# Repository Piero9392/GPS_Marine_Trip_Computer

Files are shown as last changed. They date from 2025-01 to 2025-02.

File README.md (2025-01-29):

# GPS Marine Trip Computer 🚤



This project is a fully functional GPS Marine Trip Computer designed for boats or other purposes. It displays real-time speed, direction, temperature, time, total odometer reading, total engine operating hours, and trip distance on an ILI9341 TFT display.

## Features
* **Speed Monitoring**: Real-time speed display in km/h.
* **Trip and Total Odometers**: Track current trip distance and total traveled distance.
* **Runtime Tracker**: Records and displays the total runtime of the engine.
* **Temperature Display**: Real-time water or ambient temperature measurement using a DS18B20 sensor.
* **GPS Data**: Displays location-based data, including time (with timezone adjustment) and heading direction.
* **EEPROM Data Persistence**: Saves total distance and runtime data to EEPROM for retrieval after a power cycle.
* **3D Printable Case**: Includes 3D files for printing a custom case and lid.

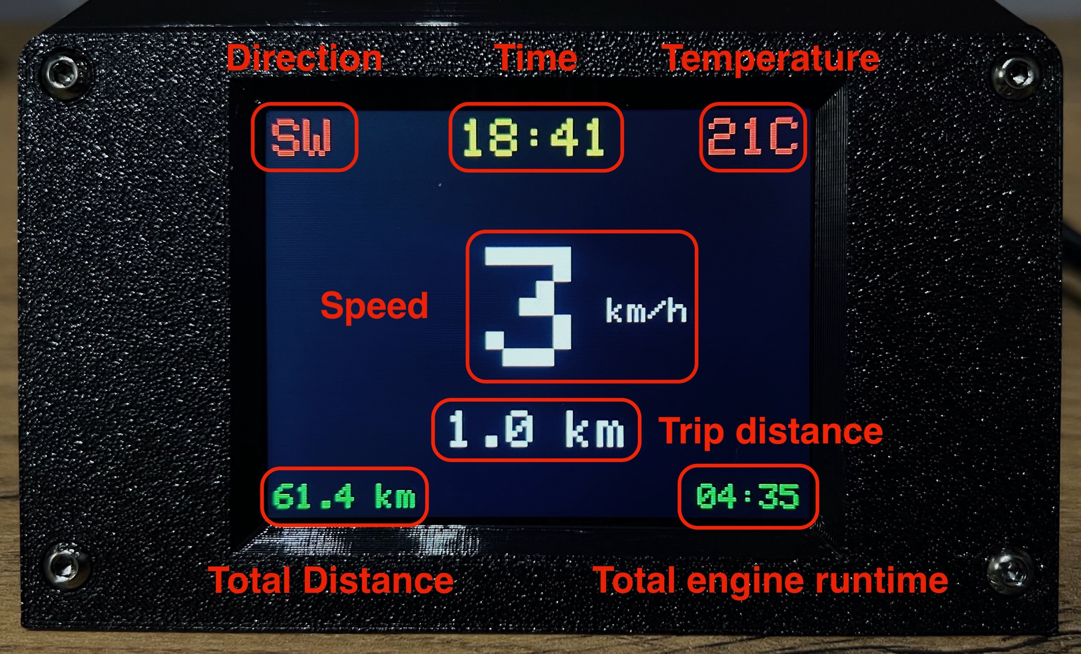
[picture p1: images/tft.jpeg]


## Hardware Requirements
* **Micrcontroller**: ESP32 WROOM 30 pins
* **Display**: ILI9341 TFT 2.8inch 240x320
* **GPS Module**: NEO-6M
* **Temperature Sensor**: DS18B20
* **4.7 kΩ pull-up resistor**
* **PCB breadboard**: 60x40mm
* **LC filter (inductor-capacitor filter)**: 0-50V, 2A
* **DC-DC converter**: MP1584 (Input: 4.5-28V, Output: set 3.3/5.0V, 2A)
* **Other Components**: AWG wires, power source, connectors, screws

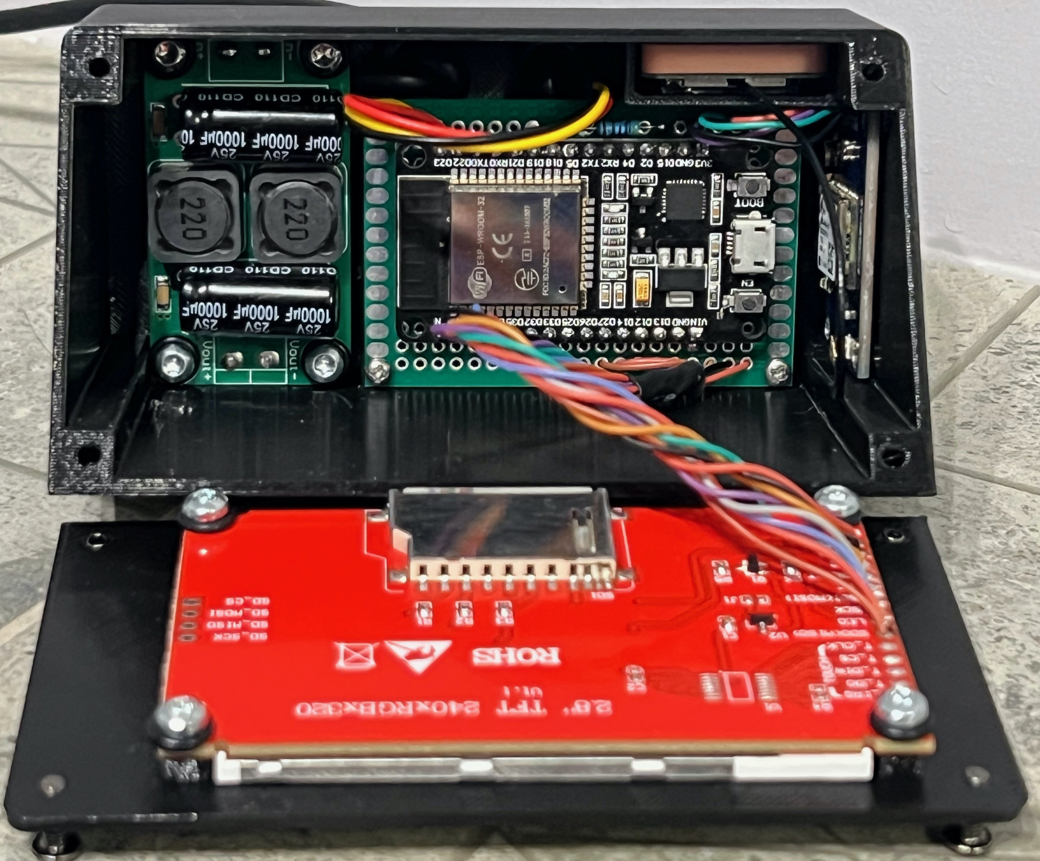
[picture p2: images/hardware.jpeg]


## Libraries Used
* `Arduino.h` - Core Arduino functionality.
* `Adafruit_GFX` - Graphs library for the TFT display.
* `Adafruit_ILI9341` - ILI9341 display driver library.
* `TinyGPS++` - GPS data parsing library.
* `SoftwareSerial` - Serial communation for the GPS module.
* `DallasTemperature` - Temperature sensor library for DS18B20.
* `OneWire` - OneWire protocol library for DS18B20 sensor.
* `EEPROM` - Library to read/write data from/to the EEPROM.

## Hardware Connections

###  Filter
* Connect the **input** of the LC filter to your **power source** (e.g., 12V boat battery).
* The LC filter is **placed before** the DC-DC converter to smooth out power supply noise.
* **Benefits of LC Filtering:**
  * **Filters out high-frequency noise** from the engine.
  * **Prevents voltage spikes** that could damage components.
  * **Improves power stability** for reliable operation.

### DC-DC Converter (MP1584)
1. **Connect the input** (VIN and GND) of the MP1584 to the **output of the LC filter**.
2. Ensure the power source voltage is within **4.5V – 28V**.
3. **Adjust Output Voltage:**
   * Connect a **multimeter** to the output terminals.
   * Turn the **adjustment potentiometer** to set the output voltage to **3.3V**.
   * Verify the voltage **before connecting the ESP32**.
4. Ensure the converter provides at least **500mA (preferably 1A or more)**.

⚠ **Note:** Do not power the ESP32 with **5V** unless using the **5V** pin (some ESP32 modules support both **5V** and **3.3V** inputs).

### Component Wiring

#### 🖥 TFT Display (ILI9341) SPI-connection:
* **MOSI**: ESP32 GPIO 23
* **MISO**: ESP32 GPIO 19
* **SCK**: ESP32 GPIO 18
* **CS**: ESP32 GPIO 5
* **RESET**: ESP32 GPIO 4
* **DC**: ESP32 GPIO 2
* **LED**: DC-DC converter Output `+`
* **VIN**: DC-DC converter Output `+`
* **GND**: DC-DC converter Output `-`

#### 📡 GPS module (Neo-6M):
* **VCC**: DC-DC converter Output `+`
* **GND**: DC-DC converter Output `-`
* **RX**: ESP32 GPIO 17 (TX2)
* **TX**: ESP32 GPIO 16 (RX2)

#### 🌡 Temperature sensor (DS18B20):
* **VCC**: DC-DC converter Output `+`
* **GND**: DC-DC converter Output `-`
* **Data**: ESP32 GPIO 15

⚠ **Note**: A **4.7kΩ pull-up resistor** is required between Data and VCC.

## How It Works
* **GPS Module**: Continuously streams data (speed, direction, time), processed using `TinyGPS++`.
* **Temperature Sensor (DS18B20)**: Measures water/ambient temperature, updated every second.
* **Display Updates**: Data is shown on the **ILI9341 TFT display**.
* **Logging**: Distance traveled and engine runtime are logged in EEPROM to persist after power cycles.
* **Effient Data Updates**: Display refreshes only on signifant data changes to optimize performance.

## Setup and Installation
1. **Install Libraries**: Install required libraries in Arduino IDE.
2. **Connect Components**: Follow the wiring diagram.
3. **Upload Code**: Flash the provided code onto the ESP32.
4. **GPS Module**: Ensure a **clear view of the sky** for accurate tracking.
5. **Power On**: Start tracking speed, temperature, and trip data!

## 3D Printable Case
This project includes **3D files for printing** a custom case and lid for protection and easy mounting.

## Future Improvements
* **External Storage**: Add SD card support to log trip data.
* **Mobile Connectivity**: Integrate **Bluetooth or Wi-Fi** for app-based tracking.
* **Additional Metrs**: Implement altitude tracking and course history.

## Author
**Igor Kolesnykov**

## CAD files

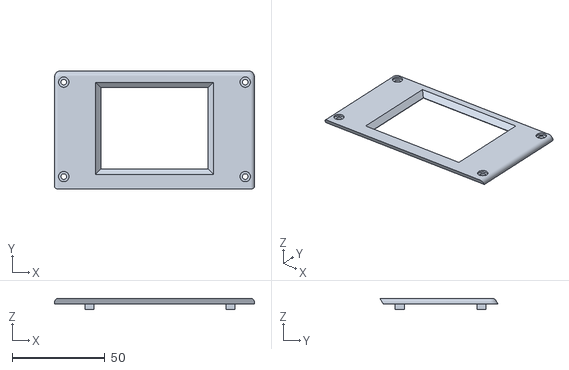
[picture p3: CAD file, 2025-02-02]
Speedometer_face_lid.stl
108.0 x 63.7 x 6.00

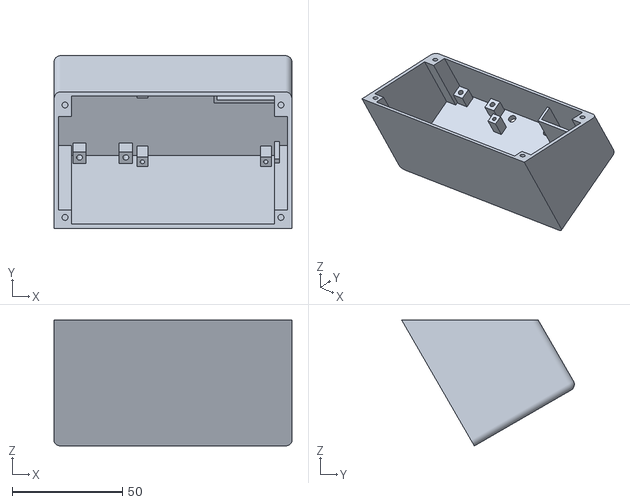
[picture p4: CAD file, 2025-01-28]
speedometer_box.stl
108.0 x 78.4 x 57.2

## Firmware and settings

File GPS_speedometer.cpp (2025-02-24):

#include <Arduino.h>
#include <SPI.h>
#include <Adafruit_GFX.h>
#include <Adafruit_ILI9341.h>
#include <TinyGPS++.h>
#include <SoftwareSerial.h>
#include <HardwareSerial.h>
#include <EEPROM.h>
#include <OneWire.h>
#include <DallasTemperature.h>

#define TFT_CS 5
#define TFT_RST 4
#define TFT_DC 2

Adafruit_ILI9341 tft(TFT_CS, TFT_DC, TFT_RST);
TinyGPSPlus gps;
HardwareSerial gpsSerial(1);

#define ONE_WIRE_BUS 15  // Change to the pin you are using for DS18B20 data
OneWire oneWire(ONE_WIRE_BUS);
DallasTemperature sensors(&oneWire);

unsigned long lastUpdateTime = 0;
String lastTimeDisplay = "";
const int timezoneOffset = 2; // Time correction for Ukraininan  time zone +2h

float tripDistance = 0;  // Distance for the current trip
float totalDistance = 0; // Total distance over all sessions
unsigned long totalRuntimeMillis = 0;

const int EEPROM_SIZE = 16;  // Increased size to store both runtime and totalDistance

void setupEEPROM() {
  EEPROM.begin(EEPROM_SIZE);
  totalRuntimeMillis = EEPROM.readULong(0);
  EEPROM.get(8, totalDistance);
}

void updateEEPROMData(unsigned long currentSessionMillis) {
  totalRuntimeMillis += currentSessionMillis;
  EEPROM.writeULong(0, totalRuntimeMillis);
  EEPROM.put(8, totalDistance);
  EEPROM.commit();
}

void speed(double speed) {
  static String lastSpeedText = "";  // Track the last displayed speed
  char speedText[10];
  sprintf(speedText, "%d", (int)speed);
  String currentSpeedText = String(speedText);

  if (lastSpeedText != currentSpeedText) {
    int16_t x1, y1;
    uint16_t w, h;
    tft.setTextSize(12);
    tft.getTextBounds(speedText, 0, 0, &x1, &y1, &w, &h);
    tft.fillRect(0, (tft.height() - h) / 2 - 10, tft.width(), h + 20, ILI9341_BLACK);

    int centerX = (tft.width() - w) / 2;
    int centerY = (tft.height() - h) / 2;

    tft.setCursor(centerX, centerY);
    tft.setTextColor(ILI9341_WHITE, ILI9341_BLACK);
    tft.print(speedText);

    tft.setTextSize(2);
    tft.setCursor(centerX + w, centerY + 30);
    tft.print(" km/h");

    lastSpeedText = currentSpeedText;
  }
}

void tripOdometer(float distanceKm) {
  static float lastTripDisplay = -1.0;
  if (fabs(distanceKm - lastTripDisplay) > 0.1) {  // Update only if a significant change
    char buffer[10];
    snprintf(buffer, sizeof(buffer), "%.1f km", distanceKm);
    tft.setTextSize(3);
    tft.setTextColor(ILI9341_WHITE, ILI9341_BLACK);
    int16_t x1, y1;
    uint16_t w, h;
    tft.getTextBounds(buffer, 0, 0, &x1, &y1, &w, &h);
    int centerX = (tft.width() - w) / 2;
    int centerY = ((tft.height() + h) / 2) + 45;
    tft.fillRect(centerX, centerY - h, w, h, ILI9341_BLACK);  // Clear previous value
    tft.setCursor(centerX, centerY);
    tft.print(buffer);
    lastTripDisplay = distanceKm;
  }
}

void totalOdometer(float distanceKm) {
  static float lastOdometerDisplay = -1.0;
  if (fabs(distanceKm - lastOdometerDisplay) > 0.1) {  // Update only if a significant change
    char buffer[10];
    snprintf(buffer, sizeof(buffer), "%.1f km", distanceKm);
    tft.setTextSize(2);
    tft.setTextColor(ILI9341_GREEN, ILI9341_BLACK);
    int16_t x1, y1;
    uint16_t w, h;
    tft.getTextBounds(buffer, 0, 0, &x1, &y1, &w, &h);
    tft.fillRect(5, tft.height() - 20, w, h, ILI9341_BLACK);  // Clear previous value
    tft.setCursor(5, tft.height() - 20);
    tft.print(buffer);
    lastOdometerDisplay = distanceKm;
  }
}

void totalRuntime() {
  static String lastRuntimeDisplay = "";  // Track the last displayed runtime
  unsigned long totalMinutes = totalRuntimeMillis / 60000;
  unsigned long hours = totalMinutes / 60;
  unsigned long minutes = totalMinutes % 60;

  char runtimeBuffer[6];
  snprintf(runtimeBuffer, sizeof(runtimeBuffer), "%02lu:%02lu", hours, minutes);
  String currentRuntimeDisplay = String(runtimeBuffer);

  if (currentRuntimeDisplay != lastRuntimeDisplay) {
    tft.setTextSize(2);
    tft.setTextColor(ILI9341_GREEN, ILI9341_BLACK);
    int16_t x1, y1;
    uint16_t w, h;
    tft.getTextBounds(runtimeBuffer, 0, 0, &x1, &y1, &w, &h);
    tft.fillRect(tft.width() - w - 5, tft.height() - 20, w, h, ILI9341_BLACK);
    tft.setCursor(tft.width() - w - 5, tft.height() - 20);
    tft.print(runtimeBuffer);
    lastRuntimeDisplay = currentRuntimeDisplay;
  }
}

void time() {
  if (gps.time.isValid()) {
    int hour = gps.time.hour() + timezoneOffset; // Time zone correction (for Ukraine +2 hours)
    if (hour >= 24) {
      hour -= 24;
    }
    char timeBuffer[6];
    snprintf(timeBuffer, sizeof(timeBuffer), "%02d:%02d", hour, gps.time.minute());

    if (lastTimeDisplay != String(timeBuffer)) {
      tft.setTextSize(4);
      tft.setTextColor(ILI9341_YELLOW, ILI9341_BLACK);
      int16_t x1, y1;
      uint16_t w, h;
      tft.getTextBounds(timeBuffer, 0, 0, &x1, &y1, &w, &h);
      tft.fillRect((tft.width() - w) / 2, 5, w, h, ILI9341_BLACK);
      tft.setCursor((tft.width() - w) / 2, 5);
      tft.print(timeBuffer);
      lastTimeDisplay = String(timeBuffer);
    }
  }
}

void direction() {
  if (gps.course.isValid()) {
    String direction;
    double course = gps.course.deg();

    if ((course >= 337.5) || (course < 22.5)) direction = "N";
    else if (course < 67.5) direction = "NE";
    else if (course < 112.5) direction = "E";
    else if (course < 157.5) direction = "SE";
    else if (course < 202.5) direction = "S";
    else if (course < 247.5) direction = "SW";
    else if (course < 292.5) direction = "W";
    else direction = "NW";

    static String lastDirectionDisplay = "";
    if (lastDirectionDisplay != direction) {
      tft.setTextSize(4);
      tft.setTextColor(ILI9341_RED, ILI9341_BLACK);
      int16_t x1, y1;
      uint16_t w, h;
      tft.getTextBounds(direction.c_str(), 10, 10, &x1, &y1, &w, &h);
      tft.fillRect(5, 5, w + 20, h, ILI9341_BLACK);  // Clear previous direction
      tft.setCursor(5, 5);
      tft.print(direction);
      lastDirectionDisplay = direction;
    }
  }
}

void temperature() {
  sensors.requestTemperatures();
  float tempC = sensors.getTempCByIndex(0);
  static int lastTemperature = -999;
  static unsigned long lastTempUpdateTime = 0;
  int currentTemperature = static_cast<int>(round(tempC));

  if (abs(currentTemperature - lastTemperature) >= 1 && (millis() - lastTempUpdateTime >= 1000)) {
    char tempBuffer[10];
    snprintf(tempBuffer, sizeof(tempBuffer), "%dC", currentTemperature);
    tft.setTextSize(4);
    tft.setTextColor(ILI9341_RED, ILI9341_BLACK); 

    int16_t x1, y1;
    uint16_t w, h;
    tft.getTextBounds(tempBuffer, 0, 0, &x1, &y1, &w, &h);

    int rectWidth = 100;
    int rectHeight = 35;
    int x = tft.width() - rectWidth;
    int y = 0;
    tft.fillRect(x, y, rectWidth, rectHeight, ILI9341_BLACK);
    tft.setCursor(tft.width() - w - 5, 5);
    tft.print(tempBuffer);

    lastTemperature = currentTemperature;
    lastTempUpdateTime = millis();
  }
}
  
void setup() {
  Serial.begin(115200);
  gpsSerial.begin(9600, SERIAL_8N1, 16, 17);
  setupEEPROM();

  tft.begin();
  tft.setRotation(1);
  tft.fillScreen(ILI9341_BLACK);
  tft.setTextColor(ILI9341_WHITE);
  tft.setTextSize(3);

  sensors.begin();  // Initialize the temperature sensor
}

void loop() {
  static unsigned long lastLoopTime = millis();
  static unsigned long lastGeneralUpdate = millis();  // Track general update timing

  while (gpsSerial.available() > 0) {
    gps.encode(gpsSerial.read());
  }

  unsigned long currentMillis = millis();
  
  // Always display temperature, total runtime, and odometer (using totalDistance)
  temperature();
  totalRuntime();
  totalOdometer(totalDistance);

  if (gps.location.isUpdated()) {
    unsigned long elapsedMillis = currentMillis - lastUpdateTime;
    float distanceIncrement = gps.speed.kmph() * (elapsedMillis / 3600000.0);
    tripDistance += distanceIncrement;
    totalDistance += distanceIncrement;
    lastUpdateTime = currentMillis;

    speed(gps.speed.kmph());
    tripOdometer(tripDistance);
    time();
    direction();
  }

  // Save runtime data every 10 seconds
  if (currentMillis - lastLoopTime >= 10000) {
    updateEEPROMData(10000);
    lastLoopTime = currentMillis;
  }

  // General update interval for non-GPS data every 1 second (adjust as needed)
  if (currentMillis - lastGeneralUpdate >= 1000) {
    lastGeneralUpdate = currentMillis;
  }
}

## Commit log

2025-01-28 Add 3d files for printing
    [speedometer_box.stl, speedometer_face_lid.stl]
2025-02-02 Update the 3D model face lid
    [Speedometer_face_lid.stl]
2025-02-24 Change the font size for Speed, Direction, Time and temperature / Change the name of functions / Change temperature algorithm updating
